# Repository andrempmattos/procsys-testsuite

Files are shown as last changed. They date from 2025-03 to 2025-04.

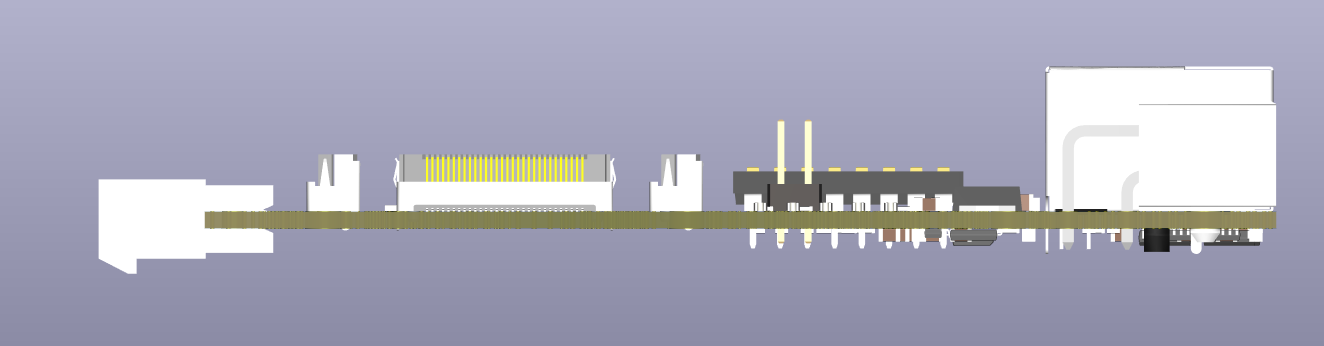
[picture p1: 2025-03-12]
instrumentation/som-exp-carrier/out/fig/pcb_side.png

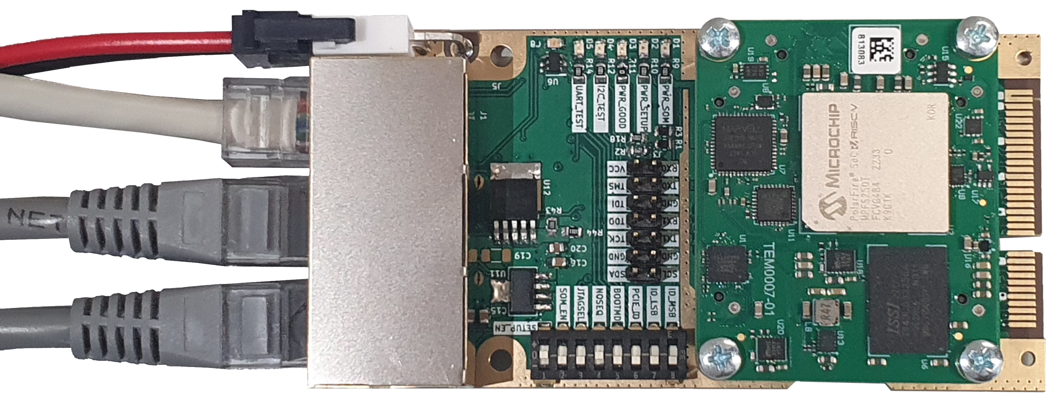
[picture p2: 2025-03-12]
instrumentation/som-exp-carrier/out/fig/pcb_photo_v1.0.png

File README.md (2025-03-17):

# procsys-testsuite
> Processing Systems Test Suite

This repository contains three elements of radiation testing of complex processing systems:
1. Test stimuli: Reliability benchmarks based on Embench
2. Test hardware: Standard and robust instrumentation for testing processing systems (SoCs) 
3. Test reporting: Standard metric for reporting the reliability of processing systems

These elements are described in detail in two main publications as well as my PhD thesis:
1. A. M. P. Mattos, D. A. Santos, and L. Dilillo, “Reliability Analysis of Baremetal and FreeRTOS Applications on Microchip PolarFire SoC RISC-V Multiprocessors Using High-Energy Protons,” in IEEE Access, 2025.
2. A. M. P. Mattos, M. R. Alas, D. A. Santos, and L. Dilillo, “Standard instrumentation for single-event effect qualification of systems-on-chip: a robust, low-cost, and open-source proposal,” in Journal of Instrumentation, 2025.

### Preview
<p align="left">
	
</p>

### License

This is a open-source project, which is distributed under different licenses (available on LICENSE.md). Feel encouraged to use and contribute back!
- CERN-OHL-P: applicable to all hardware and FPGA sources
- GPL-3.0: applicable to the software benchmarks
- MIT: applicable to the scripts

### Acknowledgement

This work was performed as part of my PhD on the Université de Montpellier, working on the Institut d'Electronique et des Systèmes and Laboratoire d’Informatique, de Robotique et de Microélectronique de Montpellier. It was supported in part by European Union’s Horizon 2020 Research and Innovation Program under Grant 101008126, in part by MCIN/AEI/10.13039/501100011033 under Project PID2022-138696OB-C21, and in part by the European Regional Development Fund (ERDF)—A way of making Europe.

<p align="left">
	
  
  
</p>

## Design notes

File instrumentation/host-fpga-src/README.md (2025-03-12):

# Sample project for SMF2000

## Requirements
> These applications must be in the PATH
- `Make`
- `Vivado`
- `Libero`

## Simulation commands

### Run simulation based on `sim/top_tb.vhd` using Vivado
```
make vivado-simulate
```
Generates output file `out/uart.log`
### Open simulation result based on `sim/top_tb_behav.wcfg`
```
make vivado-open-sim
```

## Synthesis commands
Synthesize the project for SMF2000 board
> all files for this project are in `fpga/` folder
```
make libero-project
make libero-bitstream
make libero-fpga
make uart
```

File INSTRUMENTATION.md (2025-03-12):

# Hardware

### Available target boards

`som-25tfe` : [Available here](https://shop.trenz-electronic.de/en/TEM0007-01-CAA11-A-Microchip-PolarFire-SoC-FPGA-25T-FE-1-GByte-LPDDR4-SDRAM-4-x-5-cm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) \
\> *Trenz Electronic SoM for MPFS 25T-FE  (TEM0007-01-CAA11-A: MPFS025T-FCVG484E)*

`som-250tfe` : [Available here](https://shop.trenz-electronic.de/en/TEM0007-01-CHE11-A-Microchip-PolarFire-SoC-FPGA-250T-FE-1-GByte-LPDDR4-SDRAM-4-x-5-cm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) \
\> *Trenz Electronic SoM for MPFS 250T-FE (TEM0007-01-CHE11-A: MPFS250T-FCVG484E)*

#### Power comsumption estimation
| Device 	| Design 	| Estimated power (W) 	| Current in VIN (mA) 	| Other stuff in VIN (mA) 	| Total in VIN (mA) 	|
|---	|---	|---	|---	|---	|---	|
| MPFS250T 	| Only HARV-SoC 	| 0.3 	| 91 	| 50 	| 141 	|
| MPFS25T  	| Only HARV-SoC 	| 0.22 	| 67 	| 50 	| 117 	|
| MPFS250T 	| Only 5x core RISC-V 	| 1.16 	| 352 	| 50 	| 402 	|
| MPFS25T  	| Only 5x core RISC-V 	| 1.1 	| 333 	| 50 	| 383 	|
| MPFS250T 	| Max FPGA/SoC utilization 	| 3.4 	| 1030 	| 150 	| 1180 	|
| 	| 	| 	| 	| Reasonable assumption:  	| 700 	|
| 	| 	| 	| 	| Power supply for max: 	| 3000 	|

### Supporting boards

> Supporting boards for debug and environmental experiments. Required for `som-25tfe` and `som-250tfe`

The need for the system is to test one or multiple daughterboards that use the Trenz connector specification, and to have peripheral breakouts from the daughterboard into the motherboard, since currently there is no physical interface to connect the board to the external world. Some design constraints are added, since the boards will be tested under irradiation, there is the need for most of the components in the motherboard to be radiation tolerant/insensitive, as this maximizes the daughterboard utilization and lifespan (it can be used in multiple experiments). The motherboard needs to take information from the daughterboard complex devices and relay it to a computer terminal that may be located up to 100 meters from the irradiation room.

| ID  | Requirement | Note |
| --- | --- | --- |
| 1 | The system should operate at a minimum frequency of 1 MHz | To have a reasonable response time in case of SEL |
| 2 | The system should operate at a max wired distance of 100 meters | Distance from the control room to the irradiation room |
| 3 | The system should be able to control peripheral devices in the motherboard | |
| 4 | The system should be able to house/connect different daughter boards | Using the Trenz connector specification |
| 5 | The system should be able to measure temperature in the irradiation room | |
| 6 | The system should be able to measure voltage/current from the daughter board | |
| 7 | The system shall have a RTC to keep track of time | |
| 8 | The system shall be able to output timing/timestamp data to a terminal computer in the control room | |
| 9 | The system shall have a watchdog to monitor daughter board hangups, log the error and restart the system | |
| 10  | The system shall be able to detect Latchups and cut the power as needed | It should log the SEL and report back to the terminal |
| 11  | The motherboard shall be able to control memories or external devices | These external devices could be connected directly to the PCB or via a ribbon. What is the most common connection type used to these devices? ==There is also a power budget requirement for this part== |
| 12  | All sensitive volumes of the devices shall be perpendicular to the beam | To maximize cross section |
| 13  | All motherboard devices shall be tolerant/inmune to ??? LET | And maybe add that they should use COTS components |
| 14  | The PCB size should be less or equal to 5x10 cm | |
| 15  | The system shall be able to interface with a host computer with minimal drivers | It should be able to plug and run into a USB 2.0 port and run from Windows/Linux |

#### SoM experiment carrier
`som-exp-carrier` : To be manufactured \
\> *Custom carrier board for Trenz Electronic SoM modules* \
\> *Fabrication files available in: `som-exp-carrier/out/fabpack_v0.1.zip`* \
\> *Designed to be used in environmental testing*

##### Component selection for `som-exp-carrier`

| Component 	 | Part Number 	 |
|--- |--- |
| Power supply 	 | LP38693MP-3.3/NOPB / MIC29302AWD |
| RS485 transceiver  	 | SN65HVD77D 	 |
| I2C Extender 	 | P82B96DR 	 |
| CAN for I2C 	 | TCAN1042HGVDRQ1 	 |
| LVDS tranceivers (JTAG) | SN65LVDT14 / SN65LVDT41 | 
| IO Extender (I2C) | TCAL9535 |
| Level shifter | SN74AXC8T245QPWRQ1 |
| Temperature sensor 	 | TMP100-Q1 	 |
| Power sensor 	 | INA3221-Q1 	 | 
| Watchdog 	 | TPS35AA38AGADDFRQ1 	 |
| Connector: RJ45 (1x3) | 09455511123 |
| Connector: Power Molex | 39-30-0020 |
| SoM daughterboard | LSHM-150-04.0-L-DV-A-S-K-TR |
| SoM daughterboard | LSHM-130-04.0-L-DV-A-S-K-TR |
| PCIe connector (straddle) | 10025026-10001TLF |
| [Extra] Housing Power Molex | 39-01-2020 |
| [Extra] Power Molex cable | 215325-1021 |

Whitepapers:
LVDS: [Extending interfaces with differential protocols](https://www.ti.com/lit/an/slla142/slla142.pdf?ts=1709477472033) \
CAN: [Reference Design for I2C Range Extension: I2C with CAN](https://www.ti.com/lit/ug/tiduei0/tiduei0.pdf?ts=1706800958116&ref_url=https%253A%252F%252Fwww.google.com%252F)

#### Experiment host board
`exp-host` : To be manufactured \
\> *Custom board for interfaces and computer access in the host side* \
\> *Fabrication files available in: `exp-host/out/fabpack_v0.1.zip`* \
\> *Designed to be used in the irradiation facilities with long cables*

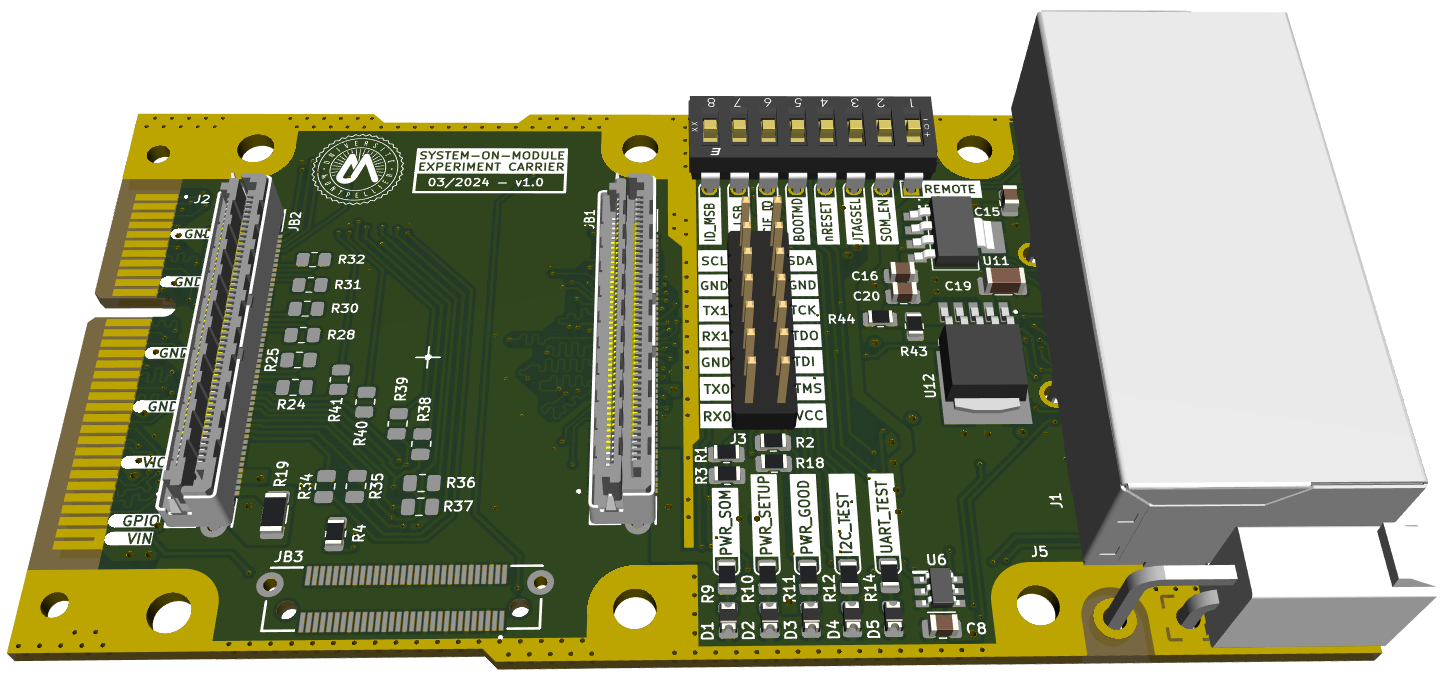
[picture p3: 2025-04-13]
instrumentation/som-exp-carrier/out/fig/pcb_3d.png

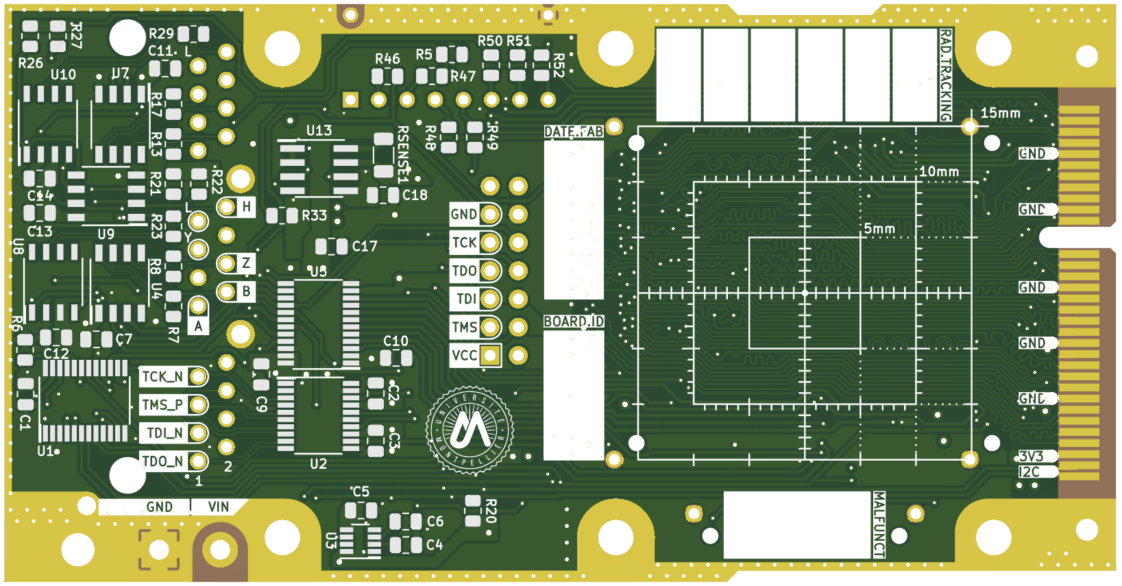
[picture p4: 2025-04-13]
instrumentation/som-exp-carrier/out/fig/pcb_bottom.png

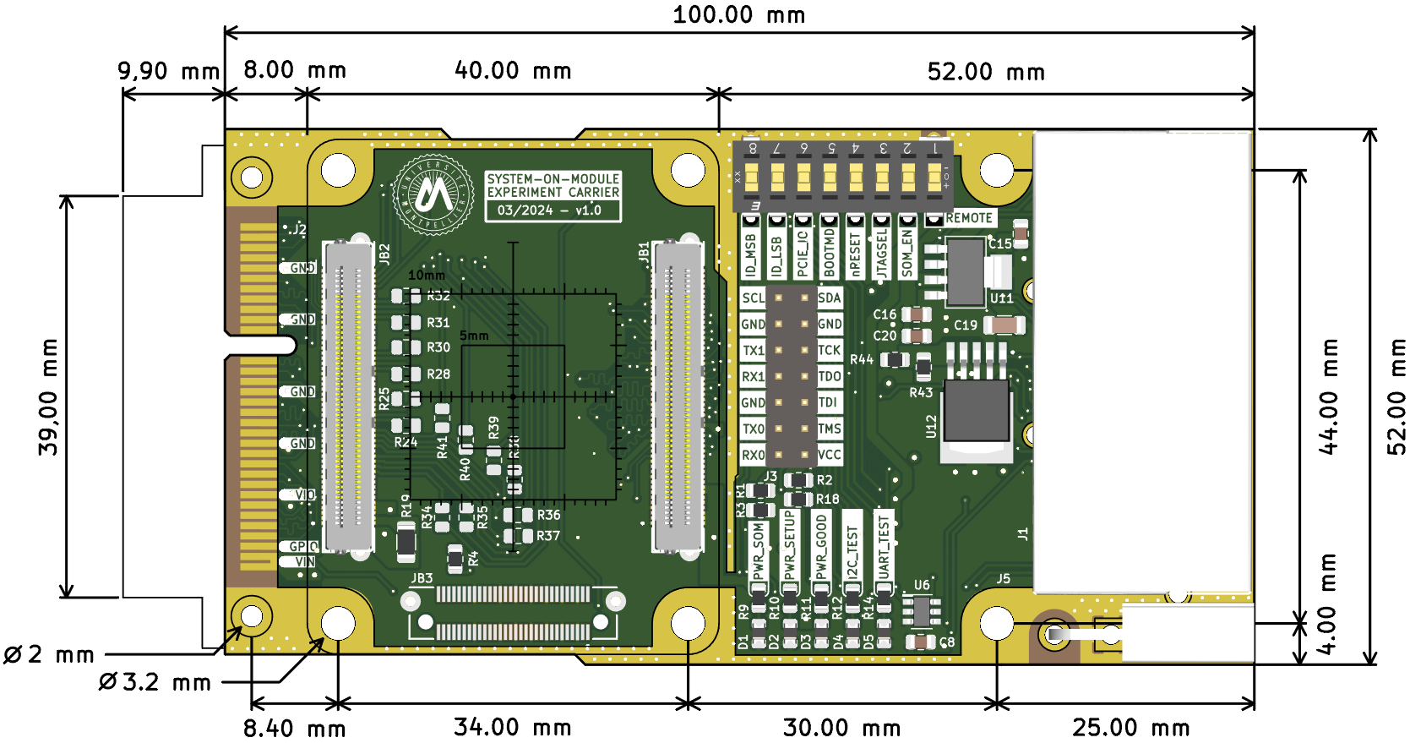
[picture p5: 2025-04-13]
instrumentation/som-exp-carrier/out/fig/pcb_top_dimensions.png

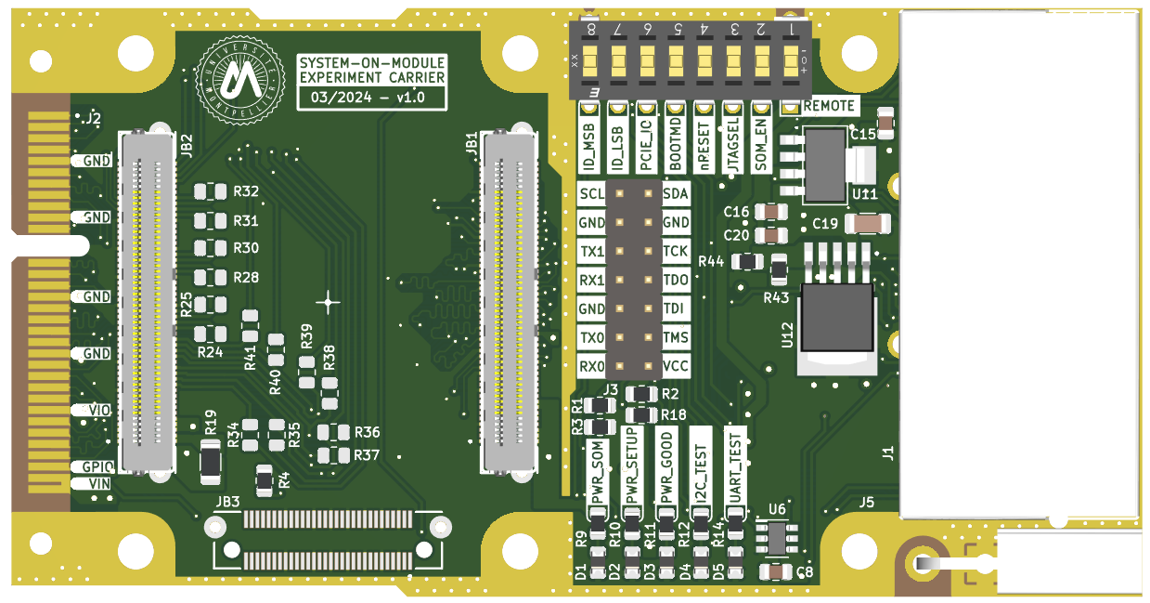
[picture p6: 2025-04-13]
instrumentation/som-exp-carrier/out/fig/pcb_top_mounted.png

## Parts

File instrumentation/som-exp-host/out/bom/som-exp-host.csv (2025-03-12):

Id | Designator | Footprint | Quantity | Designation | Supplier and ref
1 | R3,R1,R4,R6,R5,R2 | R_0805_2012Metric_Pad1.20x1.40mm_HandSolder | 6 | 1k
2 | H2,H3,H4,H1 | MountingHole_2.7mm_Pad | 4 | MountingHole_Pad
3 | J3 | 5710500 | 1 | 571-0100
4 | J2 | 5710500 | 1 | 571-0500
5 | LED6,LED4 | LED_0805_2012Metric_Pad1.15x1.40mm_HandSolder | 2 | ORANGE
6 | REF** | Fiducial_0.5mm_Mask1.5mm | 1 | Fiducial_0.5mm_Mask1.5mm
7 | C7,C6 | C_0805_2012Metric_Pad1.18x1.45mm_HandSolder | 2 | 0.1u
8 | J7 | IDC-Header_2x05_P2.54mm_Horizontal | 1 | Conn_02x05_Odd_Even
9 | J5 | BarrelJack_GCT_DCJ200-10-A_Horizontal | 1 | Barrel_Jack_Switch
10 | J6 | PinHeader_1x06_P2.54mm_Vertical | 1 | Header_2.54mm
11 | LED1,LED2 | LED_0805_2012Metric_Pad1.15x1.40mm_HandSolder | 2 | GREEN
12 | J1 | 09455511123 | 1 | 09455511123
13 | U14 | SN65LVDT41PW | 1 | SN65LVDT41PW
14 | U2 | FT4232H-56Q-Module | 1 | FT4232H-56Q-Module
15 | U1 | SMF2000 | 1 | SMF2000
16 | LED3,LED5 | LED_0805_2012Metric_Pad1.15x1.40mm_HandSolder | 2 | BLUE
17 | R19,R15,R18,R16,R20,R17 | R_0805_2012Metric_Pad1.20x1.40mm_HandSolder | 6 | 10kR
18 | U9,U5 | SN65HVD30MDREP | 2 | SN65HVD30MDREP
19 | C8,C11,C9,C10,C12 | C_0805_2012Metric_Pad1.18x1.45mm_HandSolder | 5 | 0.1uF
20 | U12,U11 | SN65HVD232D | 2 | SN65HVD232D
21 | R9,R12,R13,R14,R10,R11 | R_0805_2012Metric_Pad1.20x1.40mm_HandSolder | 6 | 100R
22 | U10 | P82B96DR | 1 | P82B96DR

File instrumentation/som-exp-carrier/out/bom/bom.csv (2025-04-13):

Id | Designator | Footprint | Quantity | Designation | Partnumber | Mouser
1 | S1 | KAD08LHGT | 1 | KAD08LHGT | KAD08LHGT | 612-KAD08LHGT
2 | D4 | D_0805 | 1 | RED | LTST-C170KRKT | 859-LTST-C170KRKT
3 | C19 | C_1206 | 1 | 100uF | GRM31CR61A107MEA8L | 81-GRM31CR61A107MA8L
4 | J3 | PinHeader_2x07_P2.54mm_Vertical | 1 | Header_2.54mm | 10-89-7140 | 538-10-89-7140
5 | R2 | R_0805 | 1 | 1k | AC0805JR-071KL | 603-AC0805JR-071KL
6 | J1 | 9455511123 | 1 | 9455511123 | 9455511123 | 617-09455511123
7 | C20,C17 | C_0805 | 2 | 10uF | C0805C106K8RAC7210 | 80-C0805C106K8R7210
8 | JB1,JB2 | LSHM-150-04.0-L-DV-A-S-K-TR | 2 | LSHM-150-04.0-L-DV-A-S-K-TR | LSHM-150-04.0-L-DV-A-S-K-TR | 200-LSHM15004LDVASK
9 | R44 | R_0805 | 1 | 1.1k | RC0805JR-071K1L | 603-RC0805JR-071K1L
10 | J5 | 39-30-020 | 1 | 39-30-0020 | 39-30-0020 | 538-39-30-0020
11 | R11 | R_0805 | 1 | 0R | AC0805JR-070RL | 603-AC0805JR-070RL
12 | R14 | R_0805 | 1 | 1.5k | AC0805JR-071K5L | 603-AC0805JR-071K5L
13 | D1,D2 | D_0805 | 2 | GREEN | LTST-C171GKT | 859-LTST-C171GKT
14 | U11 | LP38693MP-3.3-NOPB | 1 | LP38693MP-3.3-NOPB | LP38693MP-3.3/NOPB | 926-38693MP-3.3/NOPB
15 | D3 | D_0805 | 1 | ORANGE | LTST-C170KFKT | 859-LTST-C170KFKT
16 | R4,R1,R3,R5,R33 | R_0805 | 5 | 100k | AC0805JR-07100KL | 603-AC0805JR-07100KL
17 | C8,C5,C10,C18,C14,C1,C12,C11,C7,C2,C9,C3,C13 | C_0805 | 13 | 0.1uF | C0805C104J5RACTU | 80-C0805C104J5R
18 | R18,R21,R47,R20,R27,R22,R49,R6,R52,R26,R51,R48,R50,R46 | R_0805 | 14 | 10k | AC0805JR-0710KL | 603-AC0805JR-0710KL
19 | C16,C15,C6 | C_0805 | 3 | 1uF | C0805C105J4RAC7210 | 80-C0805C105J4RACLR
20 | U6 | TMP100NA3K | 1 | TMP100NA/3K | TMP100NA/3K | 595-TMP100NA/3K
21 | R9,R10 | R_0805 | 2 | 750R | AC0805JR-07750RL | 603-AC0805JR-07750RL
22 | R19 | R_1206 | 1 | 0R | AC1206FR-070RL | 603-AC1206FR-070RL
23 | D5 | D_0805 | 1 | BLUE | LTST-C171TBKT | 859-LTST-C171TBKT
24 | J2 | 10025026-10201TLF | 1 | 10025026-10201TLF | 10025026-10201TLF | 649-1025026-10201TLF
25 | R43 | R_0805 | 1 | 1.8k | AC0805JR-071K8L | 603-AC0805JR-071K8L
26 | R12 | R_0805 | 1 | 470R | SR0805JR-7W470RL | 603-SR0805JR-7W470RL
27 | U12 | MIC29302AWD | 1 | MIC29302AWD | MIC29302AWD | 998-MIC29302AWD
28 | R29,R8,R7,R23,R17,R13 | R_0805 | 6 | 100R | AR0805JR-07100RL | 603-AR0805JR-07100RL
29 | U1 | TCA9535PWR | 1 | TCA9535PWR | TCA9535PWR | 595-TCA9535PWR
30 | U7,U4 | SN65HVD30MDREP | 2 | SN65HVD30MDREP | SN65HVD30MDREP | 595-SN65HVD30MDREP
31 | RSENSE1 | R_1206 | 1 | 0.02R | PA1206FRE070R02Z | 603-1206FRE070R02Z
32 | U5 | SN74AXC8T245QPWRQ1 | 1 | SN74AXC8T245QPWRQ1 | SN74AXC8T245QPWRQ1 | 595-74AXC8T245QPWRQ1
33 | U10,U8 | SN65HVD232D | 2 | SN65HVD232D | SN65HVD232DR | 595-SN65HVD232DR
34 | U9 | P82B96DR | 1 | P82B96DR | P82B96DR | 595-P82B96DR
35 | C4 | C_0805 | 1 | 0.039uF | GRM2195C2A393JE01J | 81-GRM2195C2A393JE1J
36 | U13 | INA219BIDR | 1 | INA219BIDR | INA219BIDR | 595-INA219BIDR
37 | U2 | SN65LVDT14PW | 1 | SN65LVDT14PW | SN65LVDT14PW | 595-SN65LVDT14PW
38 | U3 | TPS35AA38AGADDFRQ1 | 1 | TPS35AA38AGADDFRQ1 | TPS35AA38AGADDFRQ1 | 595-S35AA38AGADDFRQ1

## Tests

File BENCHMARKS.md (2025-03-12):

# Software

This folder contains base files for the proposed reliability benchmarks based on Embench v1.0. These are not complete source files, nor ported to a specific platform, instead they provide the modified Embench as a library and a pseudo main.c to show an usage example. 

Benchmark created based on `Embench 1.0`.

| Workload | Description | Branch | Memory | Compute | Floating Point | Dynamic Alloc | Included  |
|---| ---| ---| ---|---|---|---|---|
| AHA_MONT64 | Montgomery multiplication | low | low | high | no | no | yes |
| CRC32 | CRC error checking 32b | high | med | low | no | no | yes |
| CUBIC | Cubic root solver | low | med | med | yes | no | yes |
| EDN | More general filter | low | high | med | no | no | yes |
| HUFFBENCH | Compress/decompress | med | med | med | no | yes | no |
| MATMULT | Integer matrix multiply | med | med | med | no | no | yes |
| MINVER | Matrix inversion | high | low | med | yes | no | yes |
| NBODY | Satellite N body, large data  | med | low | high | yes | no | yes |
| NETTLE_AES | Encrypt/decrypt | med | high | low | no | no | yes |
| NETTLE_SHA256  | Crytographic hash | low | med | med | no | no | yes |
| NSICHNEU | Large - Petri net | med | high | low | no | no | yes |
| PICOJPEG | JPEG | med | med | high | no | no | no |
| QRDUINO | QR codes | low | med | med | no | yes | no |
| SGLIB_COMBINED | Simple Generic Library for C  | high | high | low | no | yes | no |
| SLRE | Regex | high | med | med | no | no | yes |
| ST | Statistics | med | low | high | yes | no | yes |
| STATEMATE | State machine (car window) | high | high | low | no | no | yes |
| UD | LUD composition int | med | low | high | no | no | yes |
| WIKISORT | Merge sort | med | med | med | no | no | yes |

## Keywords on UART log
- `[INIT]` marks application start
- `[INIT_HART1]` marks HART1 start
- `[BOARD]` board id
- `[APP]` application identifier
- `[VERSION]` version
- `[RST]` last reset cause
- `[HARTn]` where `n` is a number from 0 to 4. Messages usually have this header to notify the message source since channel is shared between all HARTs.
- `[BENCHMARK_START]` marks the benchmark start
- `[BENCHMARK_END]` marks the benchmark end
- `[BENCHMARK_ERROR]` represents a workload error in the specific cycle. It includes which workload failed, when it failed and the number of failures.
- `[ERROR]` used for CACHE L2 and BEU errors
- `[INJECT]` used to notify when a fault is injected
- `[TRAP]` in `mss_mtrap.c` is used for getting exceptions 
- `[WDT1]` when HART1 stop responding
- `[TVS]` temperature and voltage sensor data

## Main modifications from original benchmark

- Merge all workloads in a single executable. The original approach makes sense for performance benchmarking (individual programs), whereas it does not work for a radiation test, in which reprogramming the device is a difficult procedure.
- Add a error check/report per workload individual execution, instead of just the last. Since radiation-induced errors can occur at any time, we need to observe all workload executions performed per cycle due to the runtime equalization `LOCAL_SCALE_FACTOR * CPU_MHZ` strategy.
- Change of main entry point and scripts infrasctructure since our purpose is different. We want to have a diverse set of workloads to expose errors during execution caused by radiation instead of assesing precise/comparable performance metrics.

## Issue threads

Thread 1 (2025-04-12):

Minor issues of v1.0

andrempmattos, 2025-04-12:
List of minor issues and possible solutions:

- [x] LVDS driver does not allow JTAG header to be used \
S. Add one option to the DIP switch to remove or not the power of LVDS

- [x] LED resistors are not properly dimensioned \
S. Green LEDs need more current, GPIO test too, and blue LED a bit less.

- [x] Pull-up for power good is too big to drive an LED \
S. Remove LED resistor and do a smaller pull-up

- [x] Pull-up from regulators create problems with the DIP switch pull-ups (different voltage levels) \
S. Remove pull-up from SOM regulator, remove pull-up from DIP in the SETUP regulator

- [ ] UART LED is too fast to be properly seen \
S. TBD

- [ ] Temperature sensor gets influenced by the regulators heat \
S. Change the position or maybe add another type of IC: EMC2101/TC621
Note: https://ww1.microchip.com/downloads/en/DeviceDoc/20001895E.pdf

- [x] I2C connected to FPGA cause communication issues
S. Remove I2C connection to FPGA

Wishlist:
- [ ] Add SOM power to debug the connector
- [ ] Improve setup power RST
- [x] Add nRST to DIP switch
- [ ] Add mode power lines option
- [ ] Add a flash memory to the board
- [ ] Add LED for SOM

andrempmattos, 2025-04-13:
The changes made cover the most important points for v1.1. The rest will be skipped to avoid further changes on a validated design.

Closed 2025-04-13.

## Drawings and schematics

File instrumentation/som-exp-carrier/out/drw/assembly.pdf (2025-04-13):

A

A

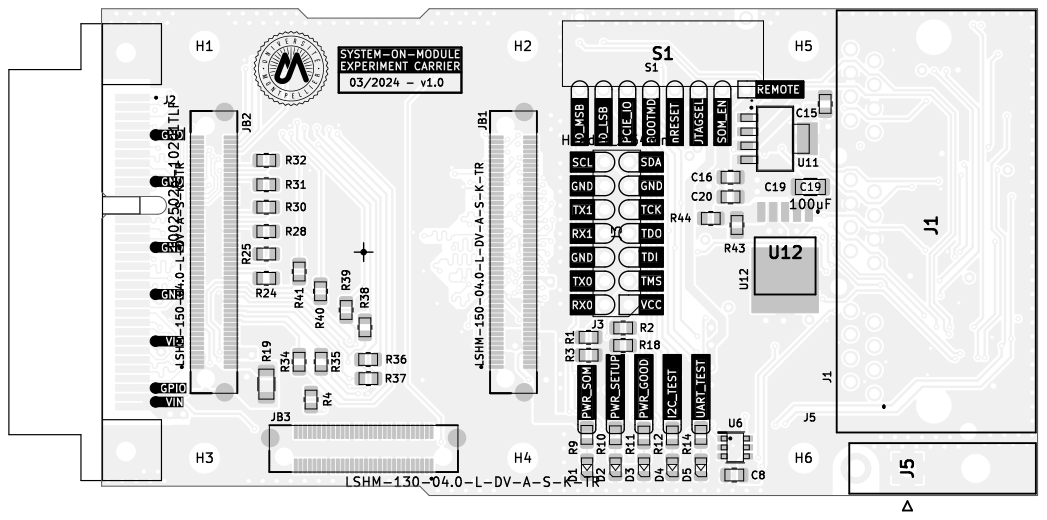
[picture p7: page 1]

File: som-exp-carrier.kicad_pcb Sheet: Black And White TOP University of Montpellier

Id: /1 Title: Experiment Carrier Board

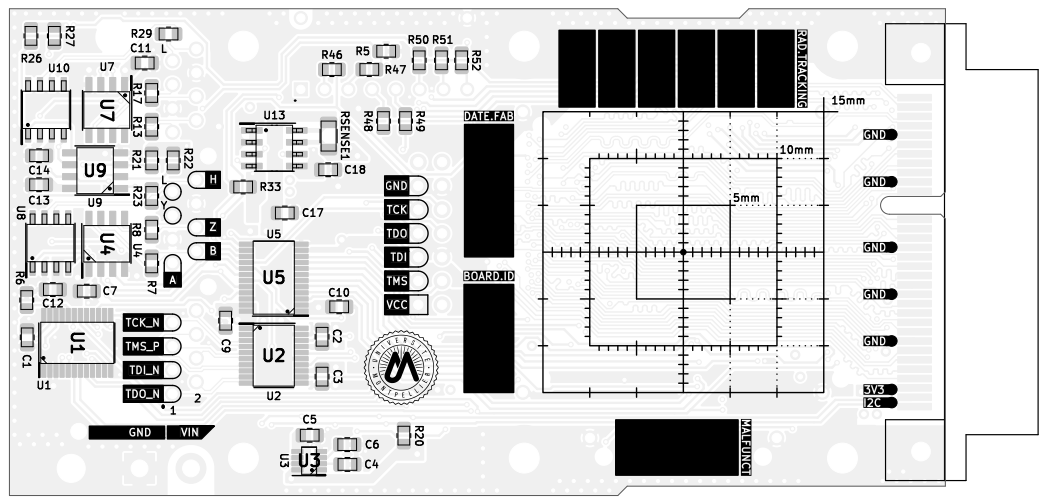
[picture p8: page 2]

File: som-exp-carrier.kicad_pcb Sheet: Black And White BOT University of Montpellier

Id: /1 Title: Experiment Carrier Board

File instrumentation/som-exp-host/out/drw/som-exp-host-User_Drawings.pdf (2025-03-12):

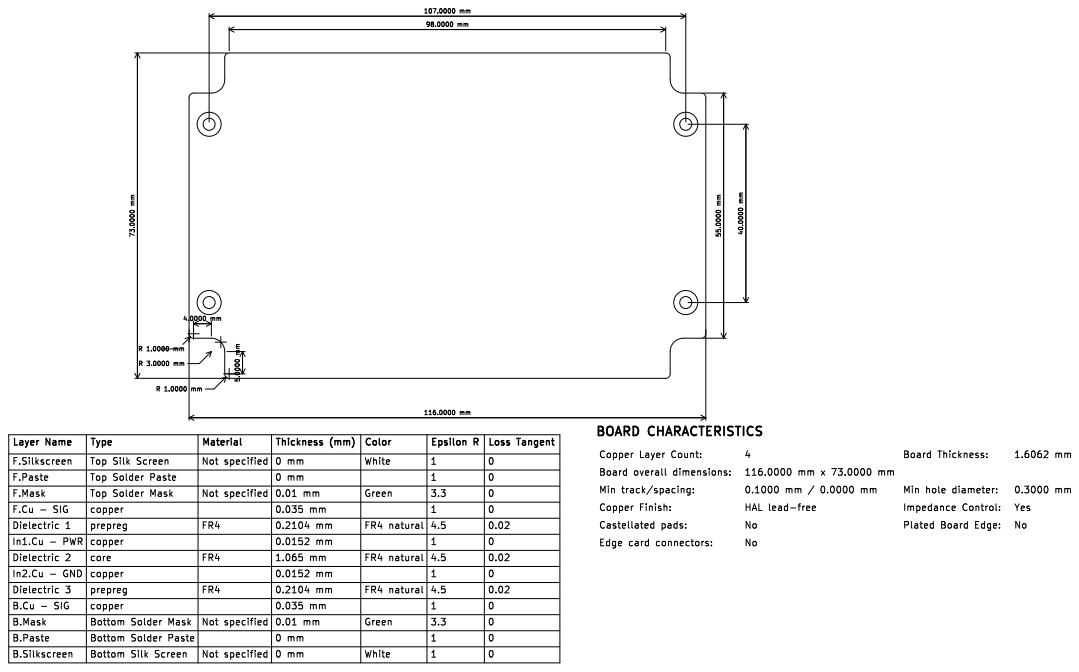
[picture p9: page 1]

Type | 0 mm | | | Loss Tangent 0 0

0 mm | Green White | 0

In2.Cu - GND | | Paste | | 0.2104 mm | | Green | | 0 Top Solder

copper prepreg | Not specified | 0.01 mm 0.035 mm

In1.Cu - PWR | | | | | | | | 0 B.Cu - SIG 0

B.Paste B.Mask | | | | | 0.0152 mm 0.2104 mm | | | 1 FR4

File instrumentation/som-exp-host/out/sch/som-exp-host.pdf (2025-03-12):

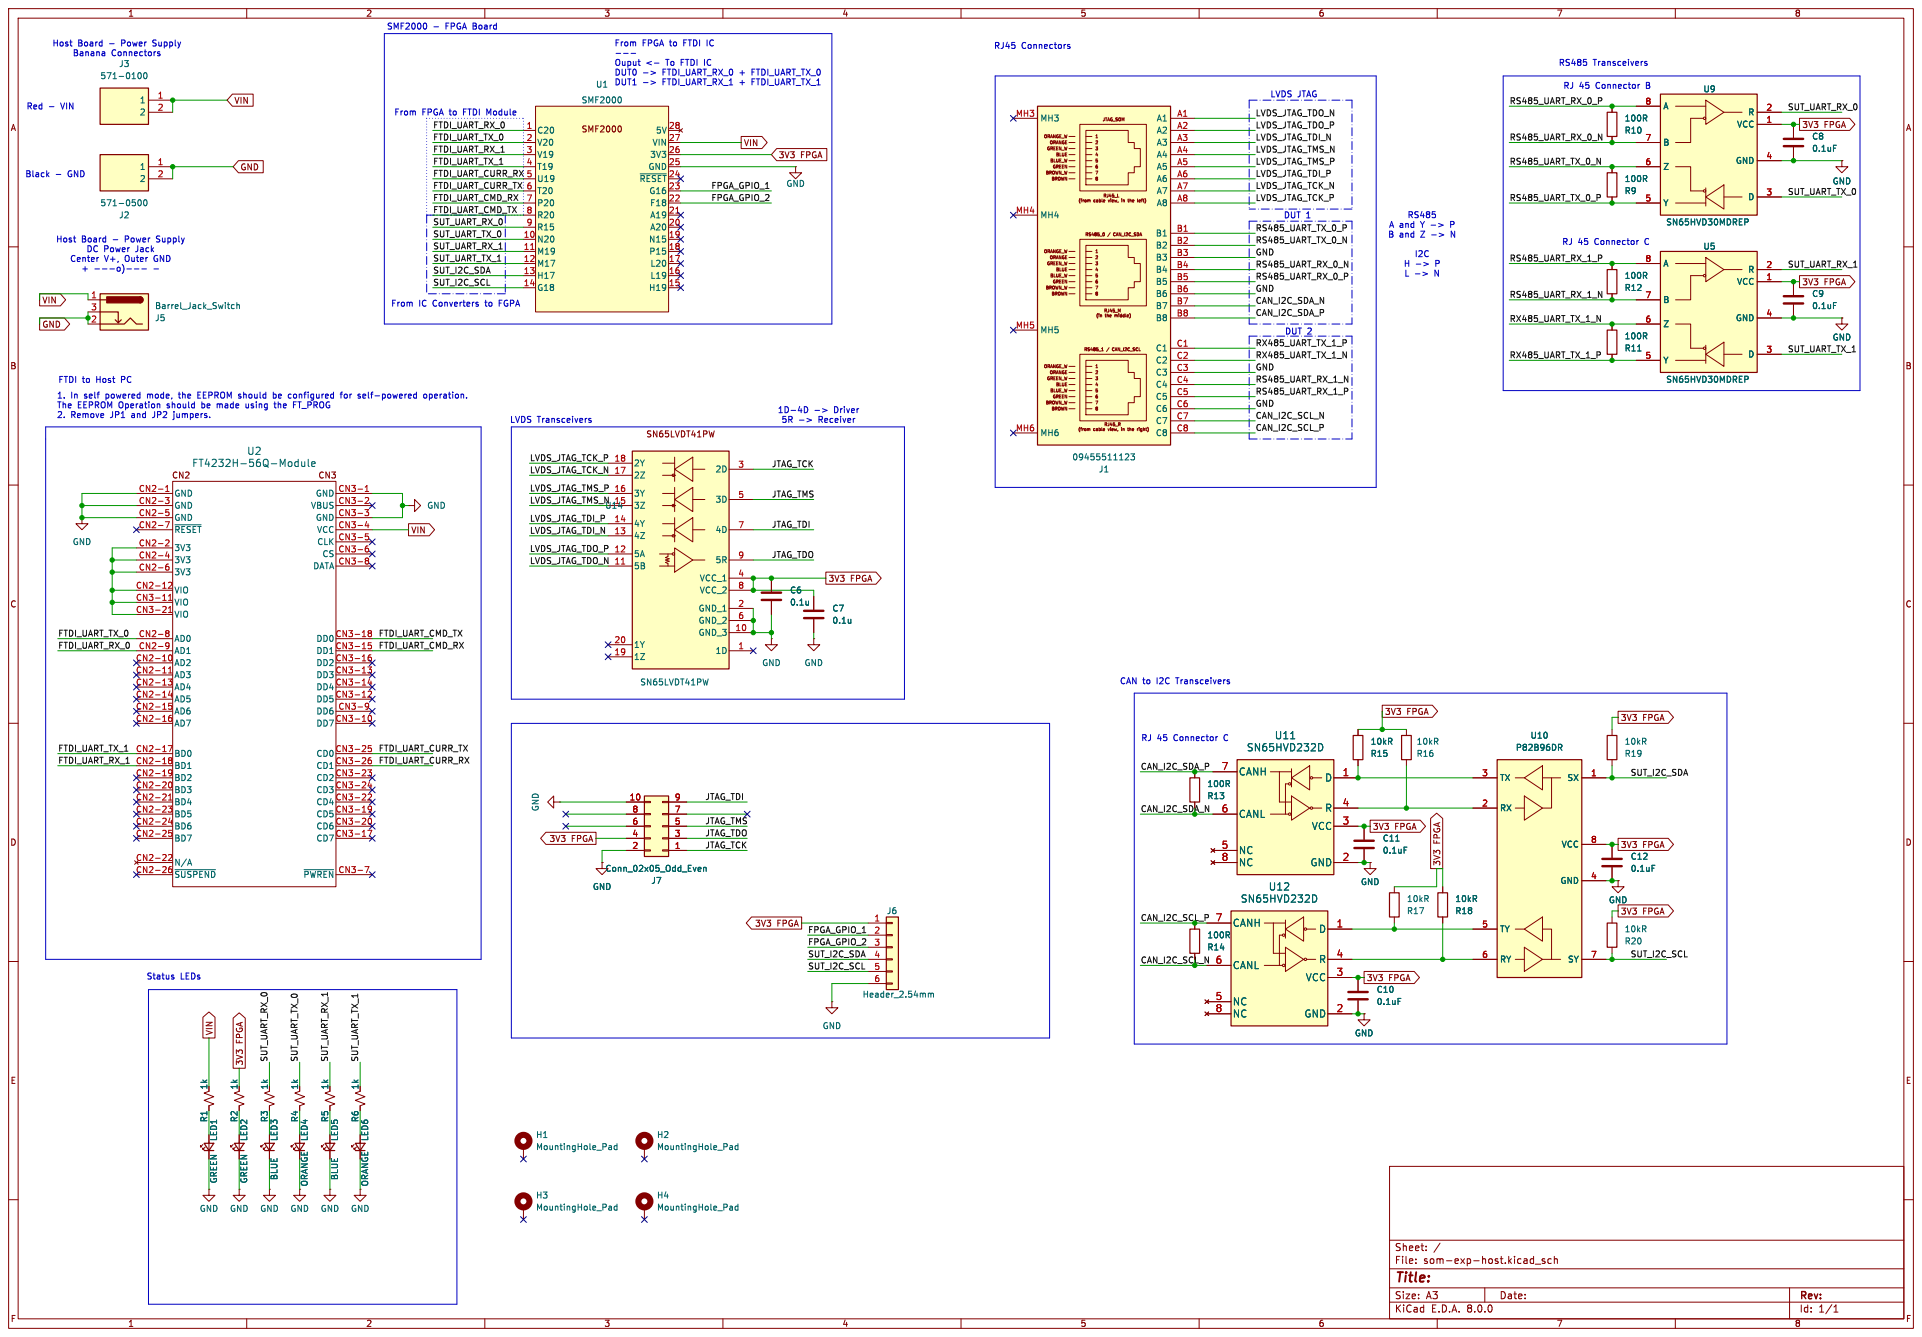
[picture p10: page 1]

SMF2000 - FPGA Board Red - VIN
RS485 Transceivers Host Board - Power Supply DC Power Jack Center V+, Outer GND

From FPGA to FTDI IC

GND LED6 ORANGE GND GND GND

Id: 1/1 Title: File: som-exp-host.kicad_sch Sheet: /

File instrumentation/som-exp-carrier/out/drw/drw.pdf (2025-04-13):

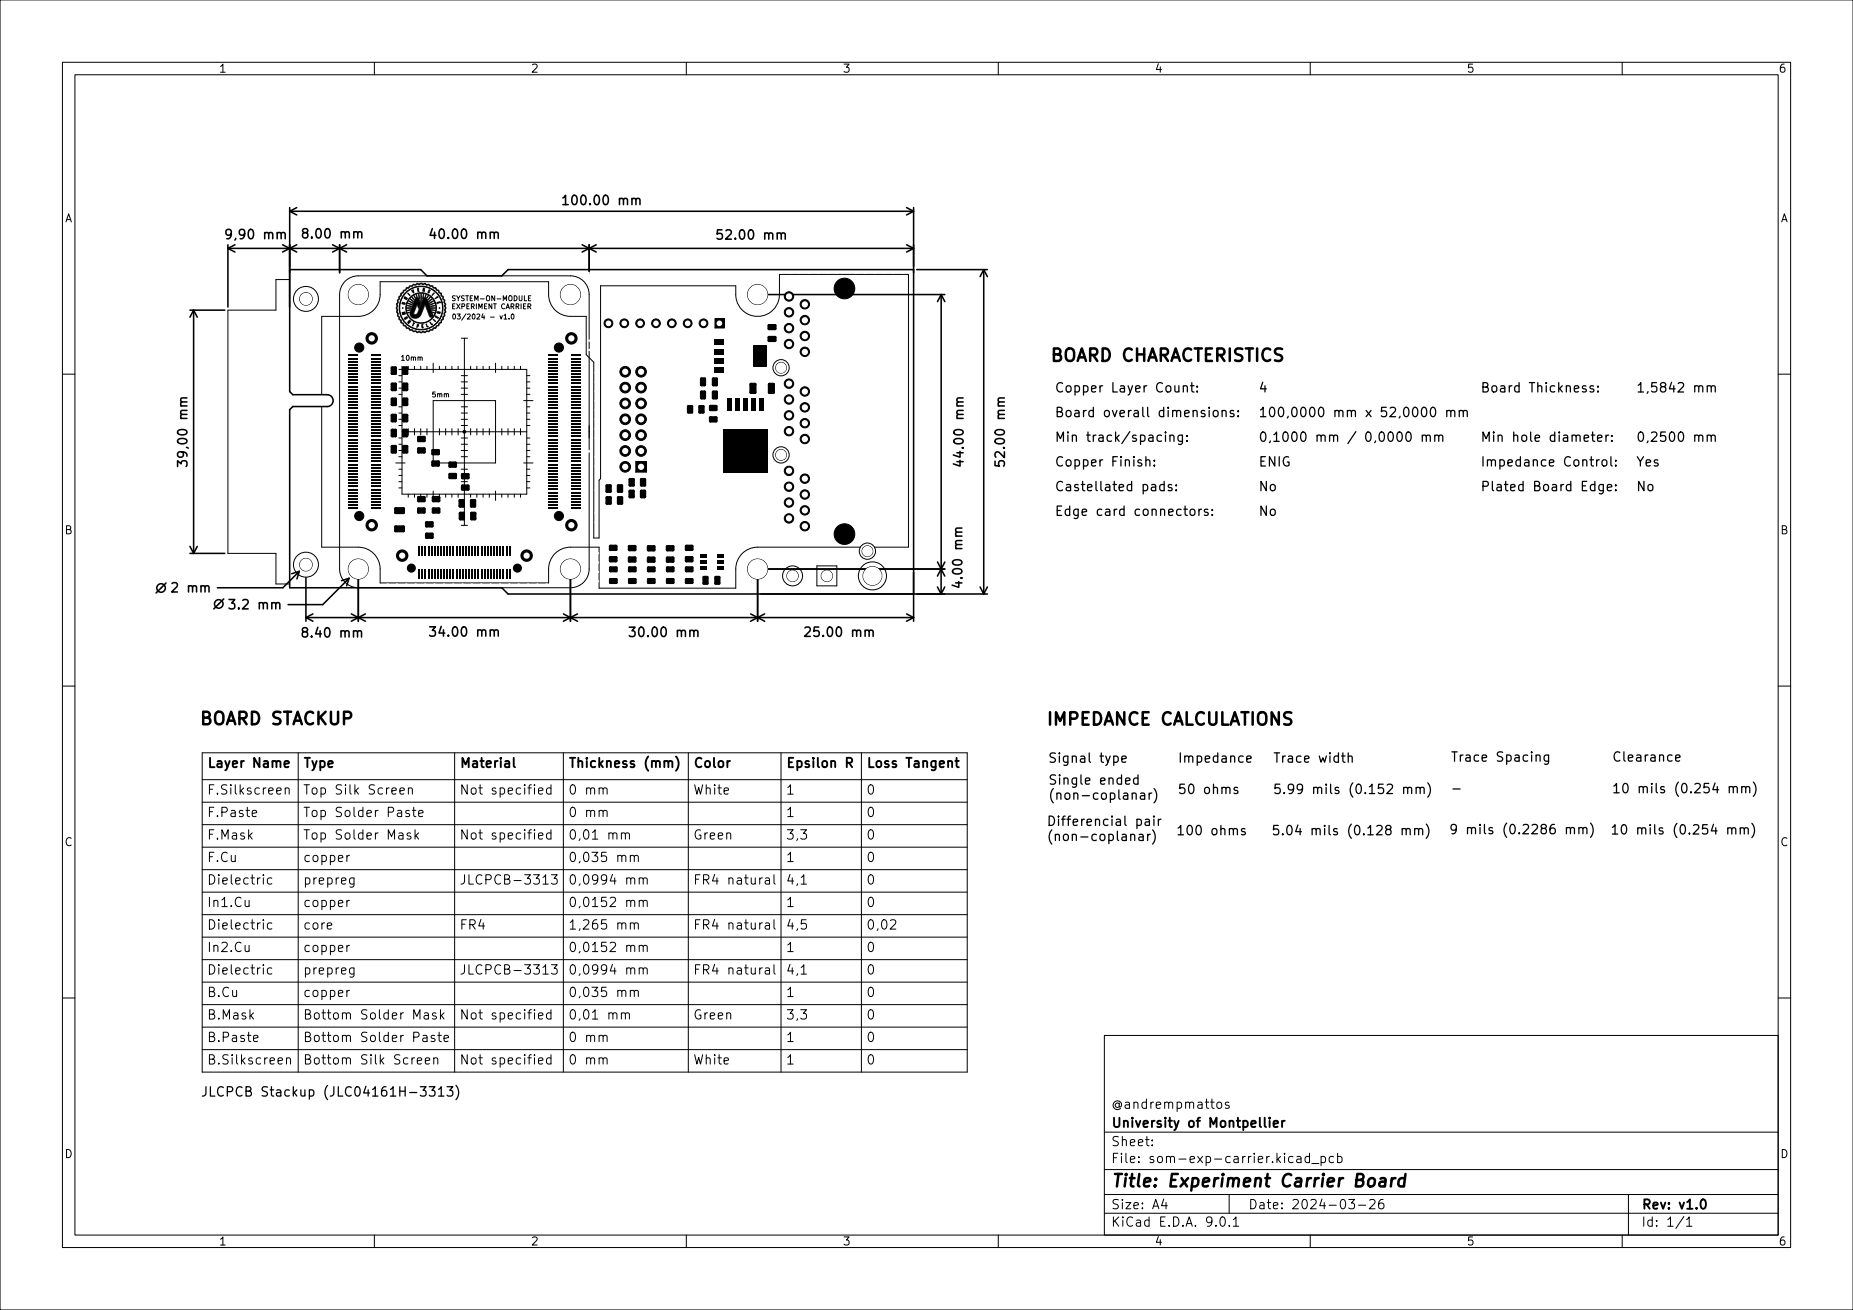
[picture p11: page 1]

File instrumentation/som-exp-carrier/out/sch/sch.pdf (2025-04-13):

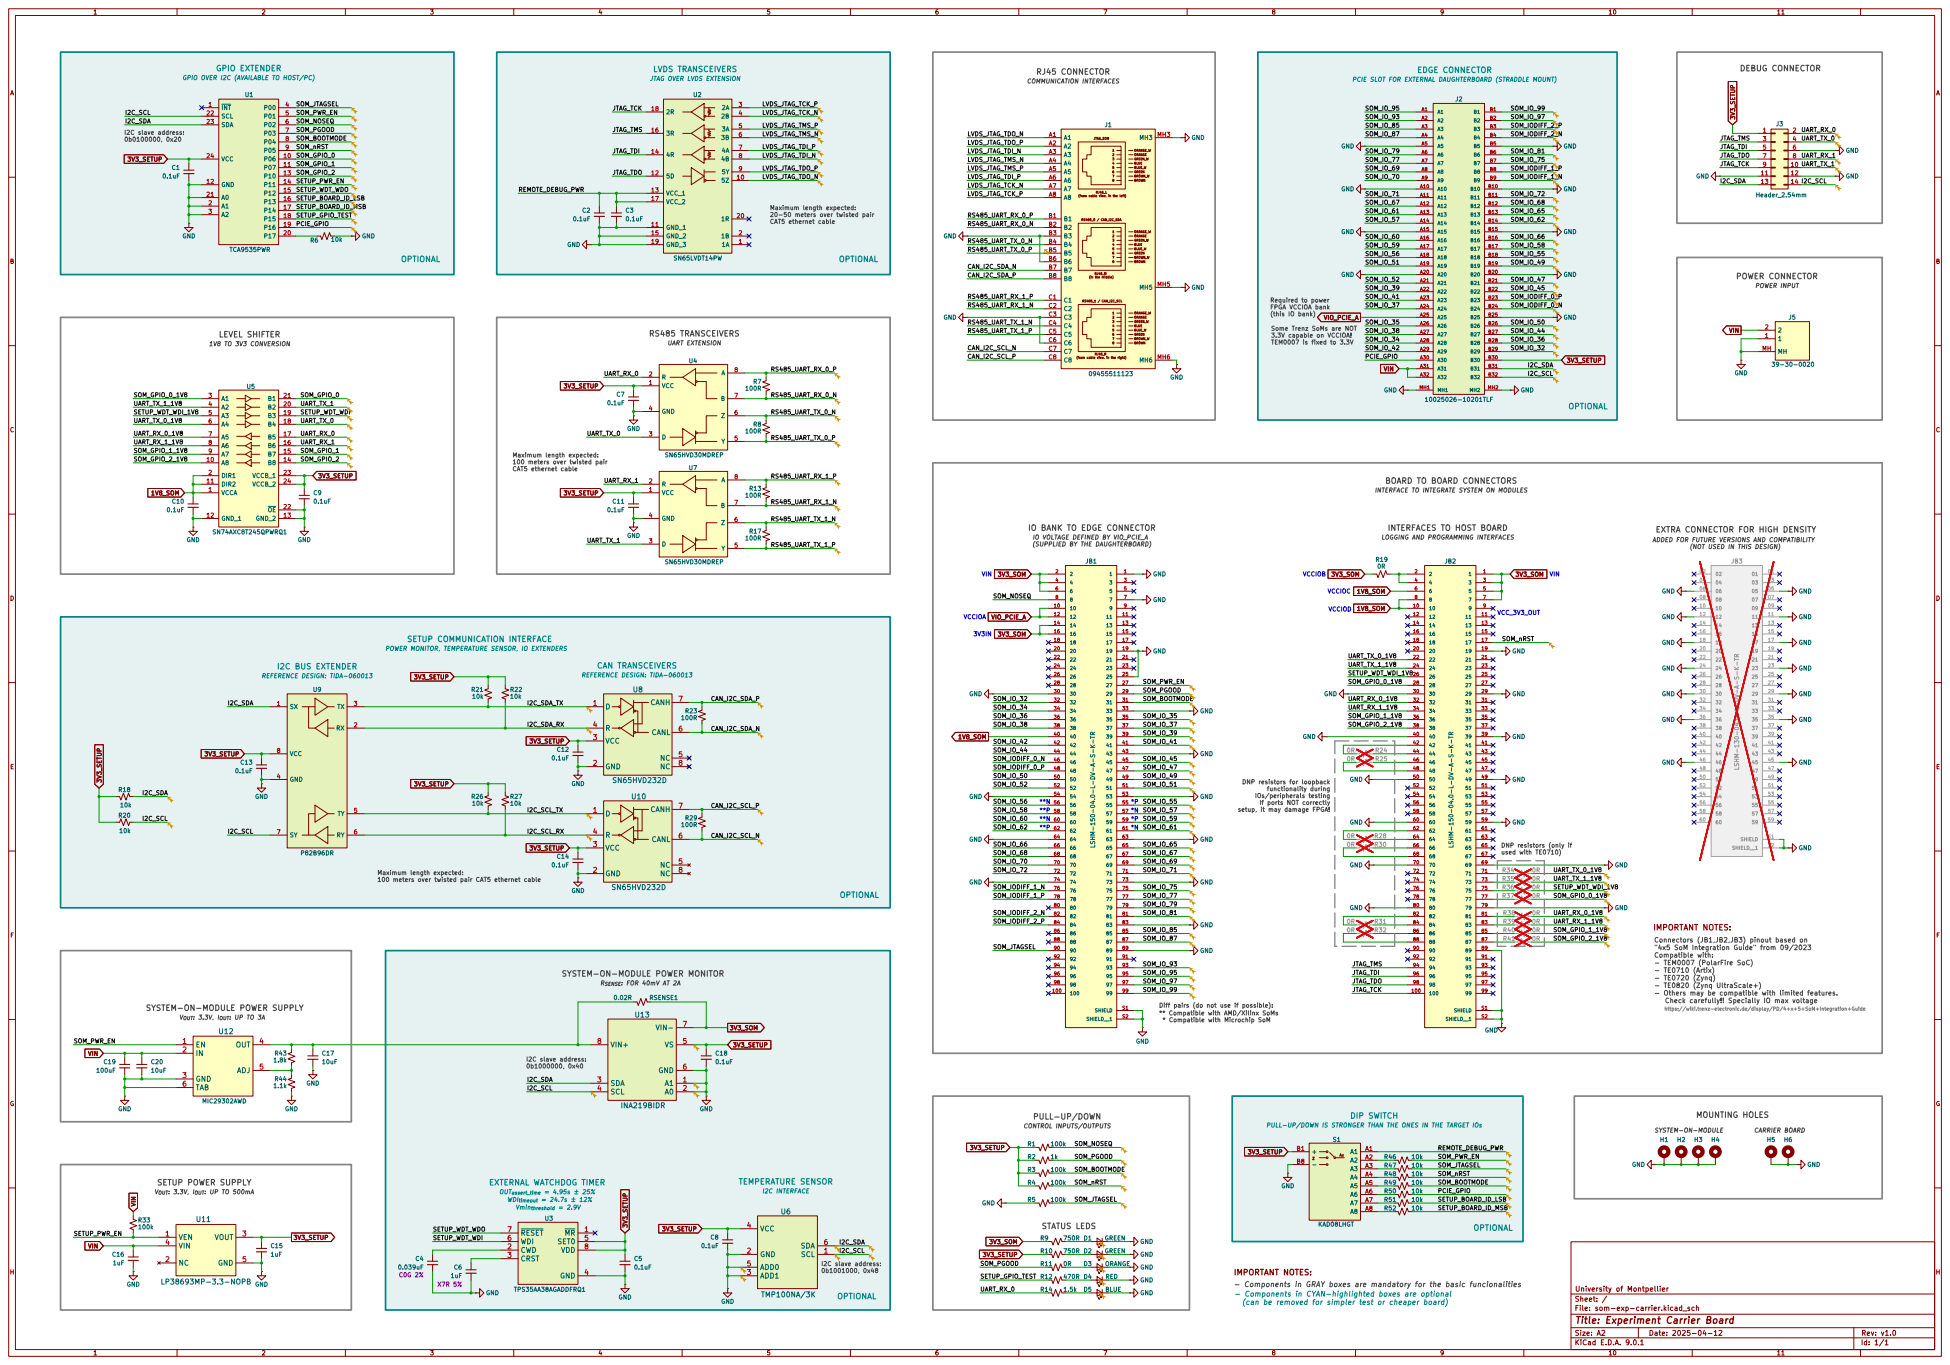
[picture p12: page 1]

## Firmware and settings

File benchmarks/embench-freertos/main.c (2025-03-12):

/**
 * u54_1.c
 *  
 *  @brief Code running on U54 core 1 (HART1)
 *    
 *   @date 01 Jun 2024 
 *   @author Andre Mattos
 * 
 */
#include <stdio.h>
#include <string.h>

#include <mpfs_hal/mss_hal.h>
#include <drivers/mss/mss_watchdog/mss_watchdog.h>
#include <drivers/mss/mss_sys_services/mss_sys_services.h>

#include "inc/common.h"
#include "inc/hooks.h"
#include "inc/embench_tasks.h"

/* Kernel includes. */
#include "FreeRTOS.h"
#include "task.h"
#include "queue.h"
#include "timers.h"
#include "semphr.h"

/**
 * The task that periodically checks that all the standard demo tasks are
 * still executing and error free.
 */
static void prvCheckTask( void *pvParameters );

mss_watchdog_config_t wd1lo_config;

/** 
 * @brief Main function for the HART1(U54_1 processor). Application code running on HART1 is placed here.
 * The HART1 goes into WFI. HART0 brings it out of WFI when it raises the first Software interrupt to this HART.
 * @return
 */
void main(void)
{
	HLS_DATA* hls = (HLS_DATA*)(uintptr_t)get_tp_reg();
    HART_SHARED_DATA * hart_share = (HART_SHARED_DATA *)hls->shared_mem;

    /* Clear pending software interrupt in case there was any.
       Enable only the software interrupt so that the E51 core can bring this
       core out of WFI by raising a software interrupt. */
    clear_soft_interrupt();
    set_csr(mie, MIP_MSIP);

    /* Put this hart into WFI. */
    do
    {
        __asm("wfi");
    }while(0 == (read_csr(mip) & MIP_MSIP));

    /* The hart is out of WFI, clear the SW interrupt. Here onwards Application
       can enable and use any interrupts as required */
    clear_soft_interrupt();

    /* Watchdog config */
    MSS_WD_get_config(MSS_WDOG1_LO, &wd1lo_config);
    wd1lo_config.forbidden_en = MSS_WDOG_DISABLE;
    wd1lo_config.time_val = 0x862000u;
    wd1lo_config.timeout_val = 0x3e8u;
    /* (0x862000 - 0x3e8) * ( 1/150MHz/256) = ~15s after system reset */
    MSS_WD_configure(MSS_WDOG1_LO, &wd1lo_config);

    log_from_appcore_noheader(hart_share, "\n[INIT_HART1]\n\n");

	while(1) 
    {
        prvSetupHardware();

        log_from_appcore(hart_share, "Creating queues...\n" );
        if (create_queues(hart_share) != 0)
        {
            log_from_appcore(hart_share, "Queues creation failed!\n");
        }
        else {
            log_from_appcore(hart_share, "Queues created successfully!\n");
        }

        log_from_appcore(hart_share, "Creating tasks...\n");
        if (create_tasks(hart_share) != 0)
        {
            log_from_appcore(hart_share, "Tasks creation failed!\n");
        }
        else {
            log_from_appcore(hart_share, "Tasks created successfully!\n");
        }

        log_from_appcore(hart_share, "[FREERTOS] Start scheduler \n");
        vTaskStartScheduler();
    }

}

/* HART1 Software interrupt handler */
void Software_h1_IRQHandler(void)
{
    uint64_t hart_id = read_csr(mhartid);
}

static void prvCheckTask( void *pvParameters )
{
    /* Demo start marker. */
    while (1)
    {
        log_from_appcore(pvParameters, "FreeRTOS Demo Start\n" );
        MSS_WD_reload(MSS_WDOG1_LO);
        vTaskDelay(500/portTICK_PERIOD_MS);
    }
    
}

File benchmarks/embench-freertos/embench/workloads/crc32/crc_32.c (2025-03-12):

/* This file is part of the Bristol/Embecosm Embedded Benchmark Suite.

   This version, copyright (C) 2013-2019 Embecosm Limited and University of
   Bristol

   Contributor James Pallister <james.pallister@bristol.ac.uk>
   Contributor Jeremy Bennett <jeremy.bennett@embecosm.com>

   This file is part of Embench and was formerly part of the Bristol/Embecosm
   Embedded Benchmark Suite.

   SPDX-License-Identifier: GPL-3.0-or-later

   Code originally from: From http://www.snippets.org/.  This original code is
   FREE with no restrictions. */

/* CRC - 32 BIT ANSI X3.66 CRC checksum files */

#include "inc/common.h"
#include <embench/support.h>

/* This scale factor will be changed to equalise the runtime of the
   benchmarks. */
#ifdef IS_SIMULATION
#define LOCAL_SCALE_FACTOR    2
#else
#define LOCAL_SCALE_FACTOR    31
#define NUMBER_OF_EXECUTIONS  (LOCAL_SCALE_FACTOR * CPU_MHZ)
#endif

#include <stdlib.h>

#include <stdio.h>
unsigned int crc32_errors;
unsigned int crc32_executions; 

#ifdef __TURBOC__
#pragma warn -cln
#endif

/**********************************************************************\
  |* Demonstration program to compute the 32-bit CRC used as the frame  *|
  |* check sequence in ADCCP (ANSI X3.66, also known as FIPS PUB 71     *|
  |* and FED-STD-1003, the U.S. versions of CCITT's X.25 link-level     *|
  |* protocol).  The 32-bit FCS was added via the Federal Register,     *|
  |* 1 June 1982, p.23798.  I presume but don't know for certain that   *|
  |* this polynomial is or will be included in CCITT V.41, which        *|
  |* defines the 16-bit CRC (often called CRC-CCITT) polynomial.  FIPS  *|
  |* PUB 78 says that the 32-bit FCS reduces otherwise undetected       *|
  |* errors by a factor of 10^-5 over 16-bit FCS.                       *|
  \**********************************************************************/

/* Some basic types.  */
typedef unsigned char BYTE;
typedef unsigned long DWORD;
typedef unsigned short WORD;

#define UPDC32(octet,crc) (crc_32_tab[((crc)^((BYTE)octet)) & 0xff] ^ ((crc) >> 8))

/* Need an unsigned type capable of holding 32 bits; */

typedef DWORD UNS_32_BITS;

/* Copyright (C) 1986 Gary S. Brown.  You may use this program, or
   code or tables extracted from it, as desired without restriction.*/

/* First, the polynomial itself and its table of feedback terms.  The  */
/* polynomial is                                                       */
/* X^32+X^26+X^23+X^22+X^16+X^12+X^11+X^10+X^8+X^7+X^5+X^4+X^2+X^1+X^0 */
/* Note that we take it "backwards" and put the highest-order term in  */
/* the lowest-order bit.  The X^32 term is "implied"; the LSB is the   */
/* X^31 term, etc.  The X^0 term (usually shown as "+1") results in    */
/* the MSB being 1.                                                    */

/* Note that the usual hardware shift register implementation, which   */
/* is what we're using (we're merely optimizing it by doing eight-bit  */
/* chunks at a time) shifts bits into the lowest-order term.  In our   */
/* implementation, that means shifting towards the right.  Why do we   */
/* do it this way?  Because the calculated CRC must be transmitted in  */
/* order from highest-order term to lowest-order term.  UARTs transmit */
/* characters in order from LSB to MSB.  By storing the CRC this way,  */
/* we hand it to the UART in the order low-byte to high-byte; the UART */
/* sends each low-bit to hight-bit; and the result is transmission bit */
/* by bit from highest- to lowest-order term without requiring any bit */
/* shuffling on our part.  Reception works similarly.                  */

/* The feedback terms table consists of 256, 32-bit entries.  Notes:   */
/*                                                                     */
/*  1. The table can be generated at runtime if desired; code to do so */
/*     is shown later.  It might not be obvious, but the feedback      */
/*     terms simply represent the results of eight shift/xor opera-    */
/*     tions for all combinations of data and CRC register values.     */
/*                                                                     */
/*  2. The CRC accumulation logic is the same for all CRC polynomials, */
/*     be they sixteen or thirty-two bits wide.  You simply choose the */
/*     appropriate table.  Alternatively, because the table can be     */
/*     generated at runtime, you can start by generating the table for */
/*     the polynomial in question and use exactly the same "updcrc",   */
/*     if your application needn't simultaneously handle two CRC       */
/*     polynomials.  (Note, however, that XMODEM is strange.)          */
/*                                                                     */
/*  3. For 16-bit CRCs, the table entries need be only 16 bits wide;   */
/*     of course, 32-bit entries work OK if the high 16 bits are zero. */
/*                                                                     */
/*  4. The values must be right-shifted by eight bits by the "updcrc"  */
/*     logic; the shift must be unsigned (bring in zeroes).  On some   */
/*     hardware you could probably optimize the shift in assembler by  */
/*     using byte-swap instructions.                                   */

/* The BEEBS version of this code uses its own version of rand, to
   avoid library/architecture variation. */
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

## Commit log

2025-03-12 Initial release of the processing systems test suite
    [bom-jlcpcb.csv, bom.csv, pickplace_top.csv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]
2025-04-12 Remove I2C from FPGA and fix PGOOD pull up value
    [som-exp-carrier.kicad_pcb, som-exp-carrier.kicad_sch]
2025-04-12 Fix LVDS power for debug, balance LEDs resistance, and add nRST to DIP switch
    [som-exp-carrier.kicad_pcb, som-exp-carrier.kicad_sch]
2025-04-13 Add fabrication files for v1.1
    [bom-jlcpcb.csv, bom.csv, pickplace.csv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]
